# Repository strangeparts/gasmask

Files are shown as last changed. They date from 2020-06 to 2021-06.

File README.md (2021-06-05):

# Open Source Gas Mask

<div align="center">
  Animation of gas mask configurations
  <p style="display: block; max-width: 800px; margin: 0 auto;" align="left">
    NOTE:<br />
    These are preliminary designs that still need testing and refinement. Do not rely on this to save your life just yet.
    <br />
    Configurations shown above are for illustrative purposes and do not imply validation. Always be sure to read and understand the documentation, recommendations, and limitations of every component you build.
    </p>
</div>

## About

This is an open source 3D printable gas mask design. It consists of 3 main components - the mask itself, the filter canister, and the exhale valve. Each component in turn may consist of multiple parts. The documents contained in this repository provide information to help you select and build each component.

## Components

### Mask

Masks are either full face or half face, depending on whether they protect the mouth/nose and eyes or just the mouth and nose. Half face masks are simpler, cheaper, and faster to make in the event that eye protection is not necessary or is accomplished with separate equipment.

All masks in this repository use 40mm NATO threads to connect to other components when necessary. This also means that commercially available 40mm NATO threaded filter canisters are directly compatible with these masks. Commercial filter canisters with different connector standards may be used with the masks in this repository by using an adapter from the `adapters` folder.

See the `masks` folder readme for a comparison of mask designs.

### Filter

If filters are commercially available, they are always preferable to homemade filters. However, in the event that filter supply is expensive or unavailable, the included designs allow for homemade filters. All masks in this repository use standard 40mm NATO threaded filter canisters, which are located in `filters/NATO_40mm`.

If an adapter is in use to convert NATO threads to a different standard, you may want to build the appropriate filter canister found in the appropriate subfolder in `filters`. This is especially useful if you wish to easily switch between commercially available filters and homemade filters without having to remove the adapter.

The filter material is activated charcoal - you can buy this at any pet store. Put a layer of cotton batting in the bottom of the canister, then fill with activated charcoal, then put another layer of cotton on top, and connect the canister into the mask. See the documentation included with the specific filter design for more detailed instructions.

### Valve

The use of an exhale valve reduces the chance of asphyxiation due to re-breathing the same air, as well as prolonging the life of the filter media and mitigating visor fogging on full face masks. All masks in this repository should contain provisions for an exhale valve. For your safety, ensure every assembled mask has an exhale valve installed and operating properly. The mask documentation should include guidance on installing the exhale valve.

See the `valves` folder readme for an overview of valves.

### Adapters

To ensure compatibility between components in this repository, all connections use standard 40mm NATO threads. As a result, adapters are required to use filter canisters of a different connector standard. The `adapters` folder contains a catalog of 3D printable adapters for converting the NATO threads of the mask to many other standards.

* When using an alternate connector type, ensure that a seal is properly made and any required gaskets or additional materials are in place.
* It may make assembly and use of the mask easier if the adapter is permanently glued to the mask. This is a good option if support for multiple connector standards is not needed.

## Safety Warnings
***This mask is still in development. You should not use this in a real world situation until the mask is done, and any testing you do should be in a controlled environment with someone else present !!!***

1. Print Material: PLA can be brittle and sharp in the event that it breaks. It is recommended to use PETG or Nylon if possible, especially if the risks of PLA shattering could be an issue in the environment you plan on using it or if you expect the mask to be subjected to stresses or impacts.
2. Face Gasket: When using a hard plastic material, it is extremely unlikely that a proper seal will form between the mask and the user's face. Some form of gasket or appropriate foam should be added around the edge of the mask to ensure an airtight seal.
3. Fit / Seal / Leak Testing: It is highly recommended to test the mask for leaks and fit quality.
4. Exhale / Vent Valve: The amount of dead space inside the mask and filters can lead to a risk of asphyxiation. All masks in this repository have provisions for installing an exhale valve. Please be sure to assemble and install one in every mask.
5. Gaskets / Glue: Every connection point between parts must have an airtight seal with the exception of filter canister lids on the dirty side of the filter media. See the documentation included with each part to ensure the proper seal is achieved. Alternatively, parts that do not need to be disassembled may be glued together with the appropriate glue.

## Contributing

Pull requests welcome! Join the discussion on [Discord](https://discord.gg/7X2bSzY).

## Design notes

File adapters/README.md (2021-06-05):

# Adapters

The masks in this repository are based on the NATO 40mm respirator thread standard. In order to allow these designs to interoperate with a wider variety of off-the-shelf components, this folder contains additional adapters which will convert the NATO threading to alternate standards. This is useful for anyone who would like to use off the shelf filters that are not NATO threaded.

## External Designs

| Filter Connector | Name / Link | Creator | Connectors Tested |
| - | - | - | - |
| 3M Bayonet | [40MM NATO (RD40x1/7) to 3M™ Filter Adapter](https://www.thingiverse.com/thing:4245358) | AgapeIngenium | &#10007; |
| AOSafety R5700 8051 Bayonet | [40MM NATO (RD40X1/7) to AOSafety® R5700 8051 Bayonet Filter Adapter](https://www.thingiverse.com/thing:4265538) | AgapeIngenium | &#10007; |
| AOSafety Threaded | [40MM NATO (RD40X1/7) to AOSafety® Threaded Filter Adapter](https://www.thingiverse.com/thing:4273365) | AgapeIngenium | &#10007; |
| Delta Plus M3000 Mars Series | [40MM NATO (RD40X1/7) to Delta Plus M3000 Mars Series Filter Adapter](https://www.thingiverse.com/thing:4311197) | AgapeIngenium | &#10007; |
| Delta Plus M6000 Jupiter Series | [40MM NATO (RD40X1/7) to Delta Plus M6000 Jupiter Series Filter Adapter](https://www.thingiverse.com/thing:4311200) | AgapeIngenium | &#10007; |
| Draeger X-plore (3000/5000 Series) | [40MM NATO (RD40x1/7) to Draeger X-plore® Filter (3000/5000 Series) Adapter](https://www.thingiverse.com/thing:4329276) | AgapeIngenium | &#10007; |
| ENHA Rockman 7300 Series | [40MM NATO (RD40x1/7) to ENHA Rockman 7300 Series Filter Adapter](https://www.thingiverse.com/thing:4329610) | AgapeIngenium | &#10007; |
| GOST | [NATO to GOST & GOST to NATO (RD40x1/7-KR40H4) Adapter Set](https://www.thingiverse.com/thing:4321450) | AgapeIngenium | &#10007; |
| Honeywell/Honeywell North | [40MM NATO (RD40X1/7) to Honeywell/Honeywell North® Filter Adapter](https://www.thingiverse.com/thing:4268775) | AgapeIngenium | &#10007; |
| Honeywell Safety Sperian / Survivair ValuAir Respirator (Bayonet) | [40MM NATO (RD40x1/7) to Honeywell Safety Sperian® /Survivair™ ValuAir® Respirator (Bayonet) Filter Adapter](https://www.thingiverse.com/thing:4345345) | AgapeIngenium | &#10007; |
| Honeywell Sperian | [40MM NATO (RD40X1/7) to Honeywell Sperian® Filter Adapter](https://www.thingiverse.com/thing:4297348) | AgapeIngenium | &#10007; |
| JSP Force8 | [40MM NATO (RD40X1/7) to JSP® Force™8 Filter Adapter](https://www.thingiverse.com/thing:4294203) | AgapeIngenium | &#10007; |
| MEDOP EUROPA Comfort Series | [40MM NATO (RD40x1/7) to MEDOP Threaded Filter (EUROPA Comfort Series) Adapter](https://www.thingiverse.com/thing:4380984) | AgapeIngenium | &#10007; |
| Milla EURMASK ETNA (Bayonet) Series | [40MM NATO (RD40x1/7) to Milla EURMASK® ETNA (Bayonet) Series Filter Adapter](https://www.thingiverse.com/thing:4342320) | AgapeIngenium | &#10007; |
| Milla EURMASK (Uno/New) Series Threaded | [40MM NATO (RD40x1/7) to Milla EURMASK® (Uno/New) Series Threaded Filter Adapter](https://www.thingiverse.com/thing:4342343) | AgapeIngenium | &#10007; |
| Moldex 7000/9000 Series EasyLock Bayonet | [40MM NATO (RD40X1/7) to Moldex® 7000/9000 Series EasyLock® Bayonet Filter Adapter](https://www.thingiverse.com/thing:4275446) | AgapeIngenium | &#10007; |
| Moldex 8000 | [40MM NATO (RD40x1/7) to Moldex® 8000 Series Filter Adapter](https://www.thingiverse.com/thing:4422042) | AgapeIngenium | &#10007; |
| MSA Bayonet | [40MM NATO (RD40X1/7) to MSA® Bayonet Filter Adapter](https://www.thingiverse.com/thing:4265715) | AgapeIngenium | &#10007; |
| MSA Comfo Classic Threaded | [40MM NATO (RD40X1/7) to MSA® Comfo Classic Threaded Filter Adapter](https://www.thingiverse.com/thing:4267676) | AgapeIngenium | &#10007; |
| MSA Phalanx | [40MM NATO (RD40x1/7) to MSA® Phalanx Filter Adapter](https://www.thingiverse.com/thing:4399965) | AgapeIngenium | &#10007; |
| Portwest Bayonet | [40MM NATO (RD40X1/7) to Portwest® Bayonet Filter Adapter](https://www.thingiverse.com/thing:4273464) | AgapeIngenium | &#10007; |
| Scott 742 Series (Bayonet) | [40MM NATO (RD40x1/7) to Scott® 742 Series (Bayonet) Filter Adapter](https://www.thingiverse.com/thing:4347531) | AgapeIngenium | &#10007; |
| Secura BC Bayonet | [40MM NATO (RD40X1/7) to Secura BC Bayonet Filter Adapter](https://www.thingiverse.com/thing:4294187) | AgapeIngenium | &#10007; |
| Spasciani Bayonet (Duetta and Duo) 2000 Series | [40MM NATO (RD40x1/7) to Spasciani Bayonet (Duetta and Duo) 2000 Series Filter Adapter](https://www.thingiverse.com/thing:4378232) | AgapeIngenium | &#10007; |
| Sundstrom SR Series (SR100/200/900) | [40MM NATO (RD40x1/7) to Sundstrom SR Series Filter (SR100/200/900) Adapter](https://www.thingiverse.com/thing:4338105) | AgapeIngenium | &#10007; |

## Misc
NATO 40mm female-female coupler: https://www.thingiverse.com/thing:4304055 by AgapeIngenium

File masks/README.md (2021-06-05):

# Masks

## Designs

| Name | Size | Ports | Description | Print Time | Status |
| - | - | - | - | - | - |
| SmoothPrintedMask | Full Face | 2x NATO | Scotty's original mask design with NATO ports | - | - |
| SplineRespirator | Half Face | 3x NATO | Untested and incomplete prototype. Features smooth contours. | - | Unfinished |

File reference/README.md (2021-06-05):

# Reference
These are bits and pieces we used in building the mask and accessories!

## NATO 40mm Thread
This pair of thread models was designed based on the NATO 40mm specification for respiratory devices. It is also known as STANAG 4155, EN 148-1, or Rd 40x1/7". These models are provided to assist with the creation of masks, filter canisters, exhale valves, etc. that are compatible with other components in this repository.

These components were designed using information from this [EN-148-1 document](https://web.archive.org/web/20210329023351/https://cdn.standards.iteh.ai/samples/60082/4152181d809d48b2968c8c22062d4d21/SIST-EN-148-1-2019.pdf).

### Male
The male thread is designed to 20mm in length in order to meet the minimum requirement of 14.5mm per the specification. This helps ensure that it will reach the back of the female thread and press against the gasket to form an airtight seal. The top of the male thread model (positive Z) is chamfered for easier alignment when attaching components together. The bottom of the male thread (resting on the Z=0 plane) is not chamfered and is intended to be fused to the rest of the component.

### Female
The female thread is designed to a depth of 12mm, with a 2mm thick backstop. The depth is intended to be shallow enough to allow any male thread which follows the specification, and thus is 14.5mm or more in length, to reach the backstop and press the gasket to form an airtight seal.

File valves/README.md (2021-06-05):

# Valves
Due to the potentially large volume of filter canisters, a one way exhale valve is required to ensure a flow of fresh air and to reduce the chance of asphyxiation. Every mask in this repository should have space for an exhale valve. Refer to the documentation accompanying the mask for placement instructions.

## Designs

| Name | Description | Print Time | Status |
| - | - | - | - |
| FullyPrintedValve | Requires no extra parts. Not a perfect seal but useful if resources are limited. Can be augmented to provide an excellent seal. | ~2h | Tested |
| BalloonValve | Requires a latex glove or thin balloon. Better if your craft skills are superior to your printer tune. | ~2h | Experimental |

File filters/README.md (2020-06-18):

# Filters

This folder contains designs for respirator filters. Designs are organized into folders based on the connector type. The masks in this repo are based on the NATO thread standard. Filters with other connector standards are available in case you want to install an adapter on your mask to make it compatible with a different standard while maintaining the ability to easily use homemade filters.

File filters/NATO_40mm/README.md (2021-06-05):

# NATO 40mm Filters

## Designs

| Name | Description | Connector Tested | Assembled Length (mm) | Internal Volume (cm<sup>3</sup>) |
| - | - | - | - | - |
| BottleFilterAdapter | Allows using plastic bottles as a filter body | &#10003; | Variable | Variable |
| CustomizableAF | Fully 3D printed filter canister body | &#10003; | 120 | ~200 |

## External Designs

> Note: These designs may not be tested or validated

| Name | Connector Tested | Assembled Length (mm) | Internal Volume (cm<sup>3</sup>) |
| - | - | - | - |
| [Reusable gas mask filter - 40mm thread by Bastrym](https://www.thingiverse.com/thing:4236518) | &#10003; |  |  |

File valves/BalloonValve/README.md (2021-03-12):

# Balloon Valve

This valve was originally designed by @sophmur for respirator and cloth mask use and posted to [Thingiverse](https://www.thingiverse.com/thing:4753245).

We have reworked the design into a NATO 40mm package for our use with this project. The assembly is very similar to the `FullyPrinterValve` since we reused much of the design.

Between the two pieces you should place a circular piece of a latex glove type material (thin, light, non-breathable). We are still working on a full assembly guide but for now we recommend marking the shape and size of the `BalloonValve-Inlet` and using scissors, you can also use a sharp knife if you find that easier.

As for assembly, if you find it difficult to stretch out the latex properly, you can put the `BalloonValve-Inlet` piece up against a vacuum cleaner to hold the membrane stretched out and then put on the `BalloonValve-Body` piece onto it. It should snap right together.

<p align="center">
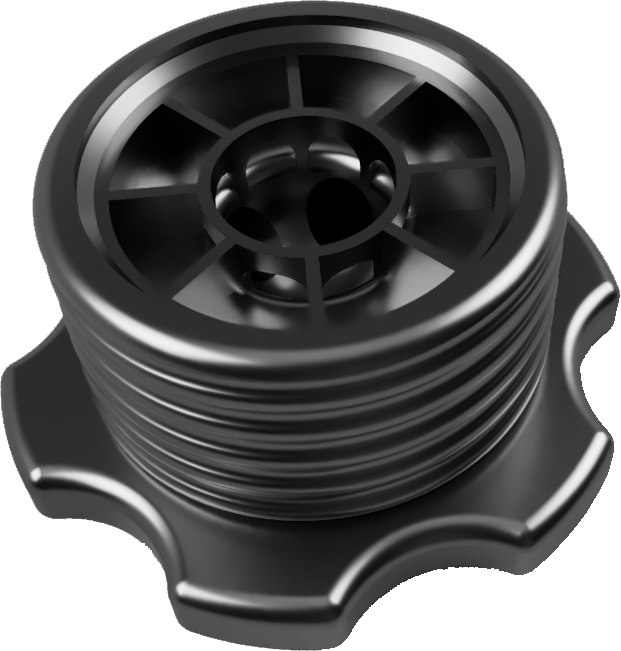
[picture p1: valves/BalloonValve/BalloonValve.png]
  
 </p>

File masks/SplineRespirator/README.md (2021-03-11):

# SplineRespirator

<p align="center">
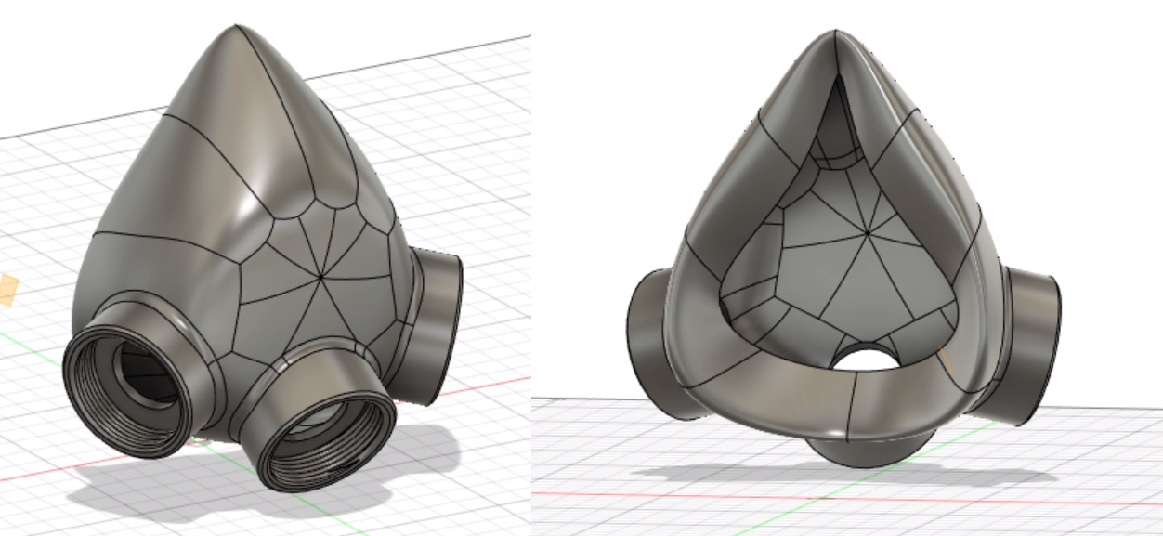
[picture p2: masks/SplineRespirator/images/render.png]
Render of the respirator body
  
</p>

This is a prototype half face respirator with 3 NATO ports. The aim of this design is to use silicone and a mold to form a better seal.

## Safety Warnings

* This design is not complete. Do not use it.

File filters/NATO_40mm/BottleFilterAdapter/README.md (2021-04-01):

# BottleFilterAdapter

<p align="center">
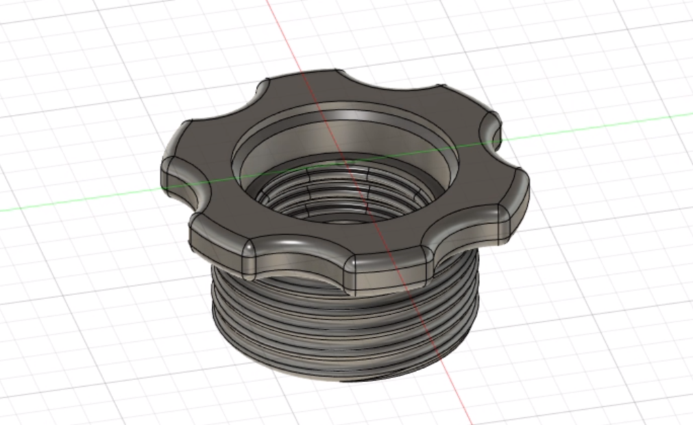
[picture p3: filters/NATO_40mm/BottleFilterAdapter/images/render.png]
Render of the respirator body
  
</p>

This component allows using water bottles / carbonated soft drink bottles to build homemade filters.

The threads on this design were created using information from [this specification](https://web.archive.org/web/20210329170423/https://www.isbt.com/assets/Threadspecs/pco1810.pdf).

## Overview

There are 2 common standards for plastic bottles - PCO-1810 and PCO-1881. The first is the older standard, and the second is the newer standard with a lower profile and less material.

Currently this design only works with PCO-1810, a PCO-1881 variant may be added later.

## Building

### Materials

1. The printed adapter
2. A plastic water bottle or soft drink bottle
3. A US #18 size o-ring (metric 1.78x18.77mm) (preferred) or glue / epoxy suitable for plastics

### Print Parameters

* Print Time: Approximately 1 hour 45 minutes
* Nozzle Size: 0.4mm
* Layer Height: 0.2mm
* Infill: 15%
* Supports: On build plate only (prevents support material in between threads, aiding with support removal)
* Walls: 2

### Assembly

1. Print the adapter in the default orientation - with the knob on the print surface.
2. Carefully remove all the support material from the bottle threads.
3. Remove the bottle cap safety seal from the bottle (the plastic ring that detaches from the cap when opening), and replace it with the o-ring. Alternatively, add glue to the bottle and adapter bottle threads.

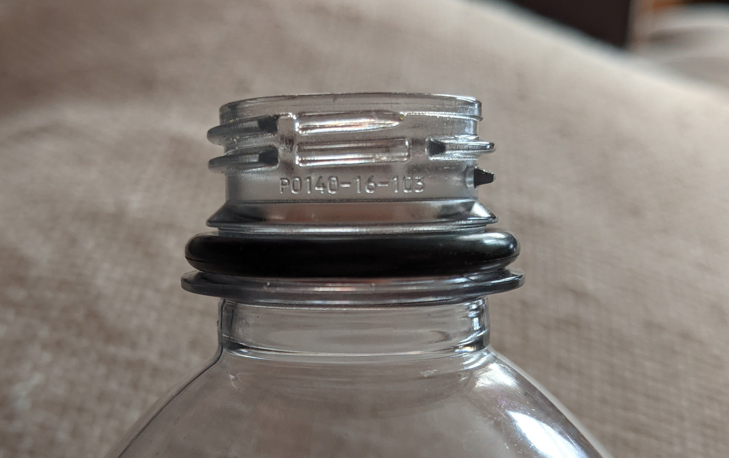
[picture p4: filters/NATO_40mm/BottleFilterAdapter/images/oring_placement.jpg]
Image of proper o-ring placement
  

4. Screw the bottle filter into the adapter until the o-ring is fully seated.

## Safety Warnings

* This design will not achieve a seal if an o-ring or glue is not used. Always test the seal to ensure your selection of o-ring/glue is effective.

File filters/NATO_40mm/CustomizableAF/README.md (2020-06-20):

# CustomizableAF

AF ofcourse meaning Air Filter

is a modular airfilter system. You can pick a main canister based on size and a cap based on your preference. The connection between those is made via an M90 thread, with tolerance added on the cap side to account for the lower precision of household 3d printers.

Feel free to itterate and create more designs.

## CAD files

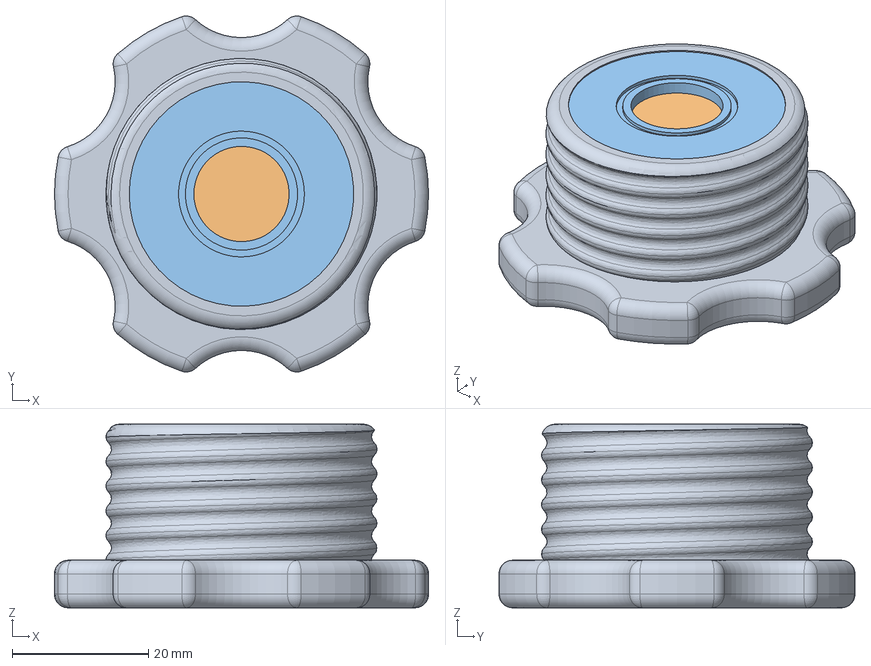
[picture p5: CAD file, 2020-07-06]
valves/FullyPrintedValve/FullyPrintedValve.stp
55.0 x 52.3 x 27.0 mm
Valve Body
Diaphragm
Inlet

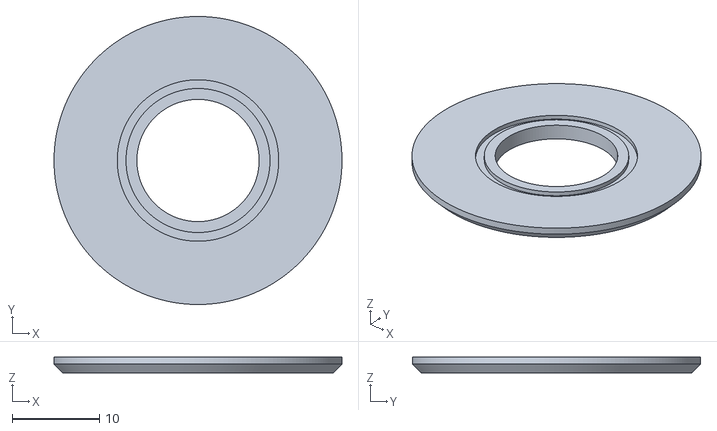
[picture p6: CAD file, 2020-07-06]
valves/FullyPrintedValve/FullyPrintedValve-Inlet.stl
33.0 x 33.0 x 1.80

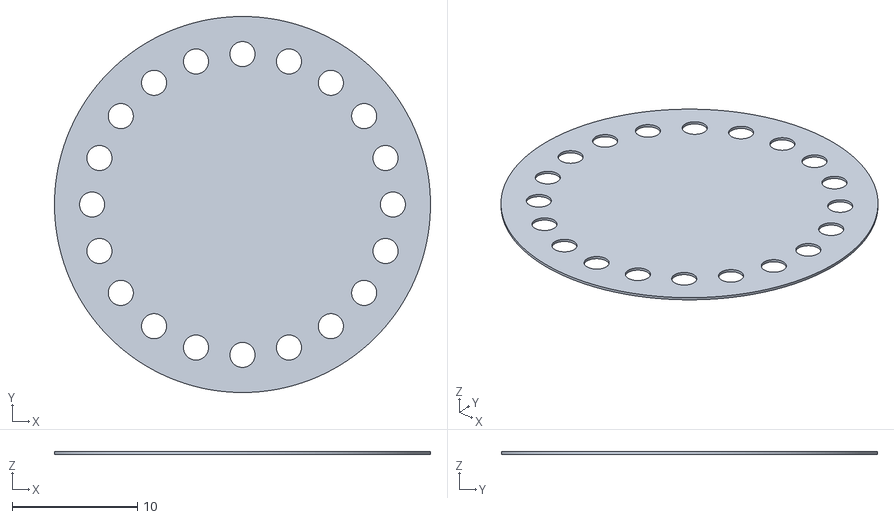
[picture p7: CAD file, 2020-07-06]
valves/FullyPrintedValve/FullyPrintedValve-Diaphragm.stl
30.0 x 30.0 x 0.2

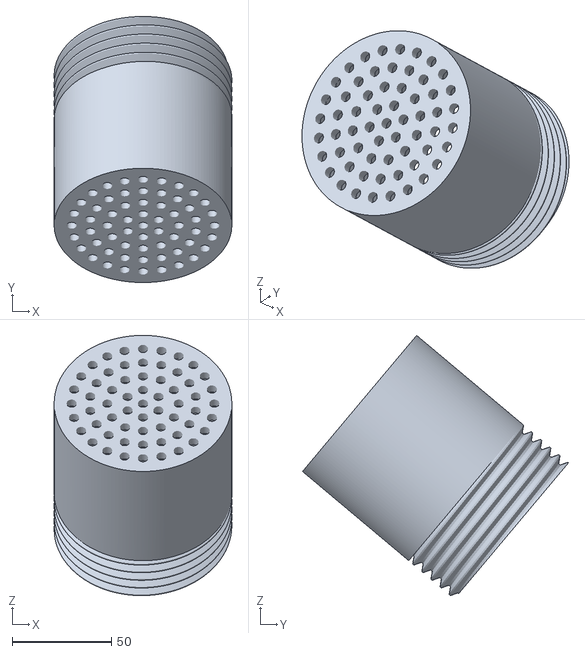
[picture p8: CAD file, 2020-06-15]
Canister.stl
89.6 x 134.2 x 131.3

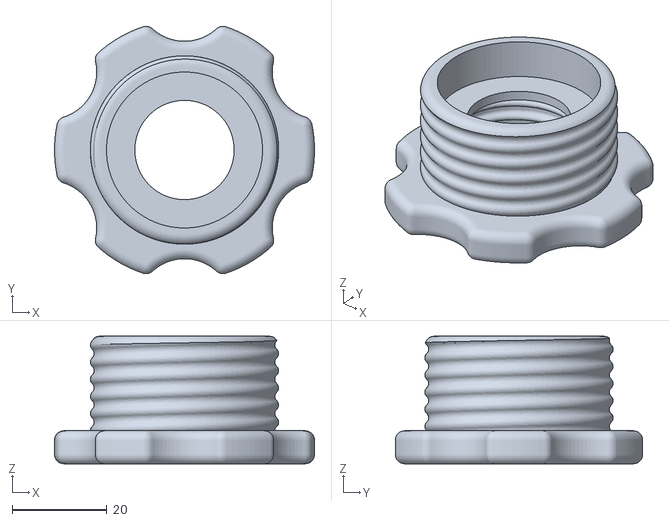
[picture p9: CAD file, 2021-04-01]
filters/NATO_40mm/BottleFilterAdapter/BottleFilterAdapter.stl
55.0 x 52.3 x 27.0

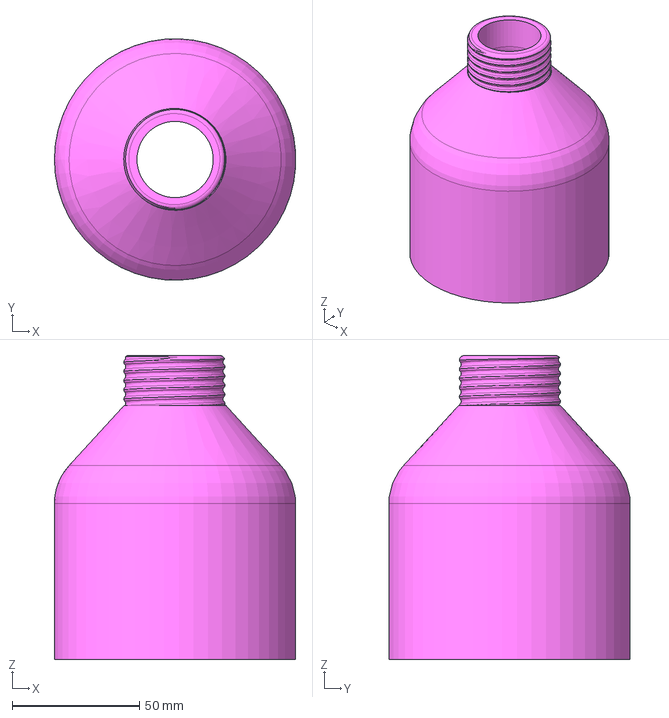
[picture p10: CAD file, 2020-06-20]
filters/NATO_40mm/CustomizableAF/120mm_Canister/120mm_Canister (NATO mount).step
94.9 x 95.0 x 119.6 mm

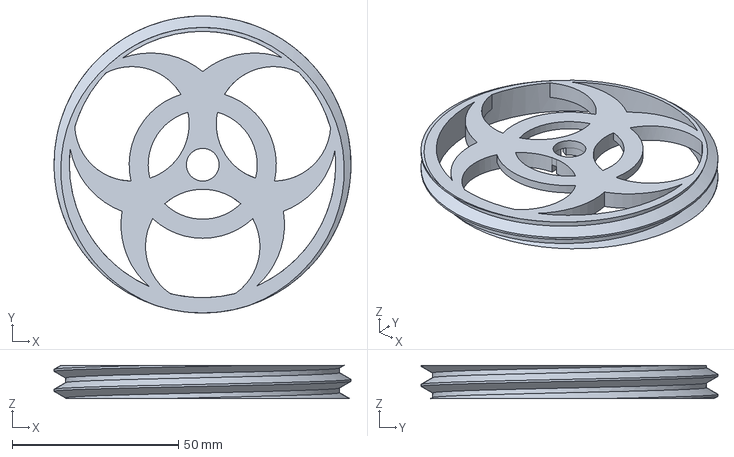
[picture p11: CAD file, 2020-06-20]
filters/NATO_40mm/CustomizableAF/SeriousOne/SeriousOne.step
89.2 x 89.2 x 10.0 mm

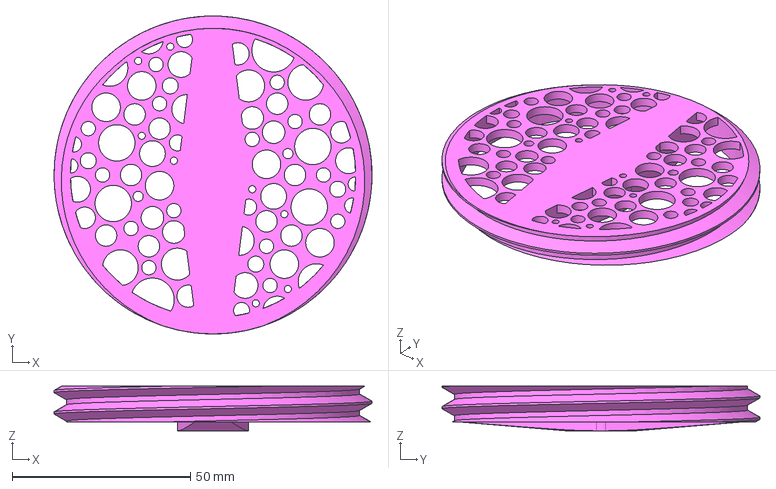
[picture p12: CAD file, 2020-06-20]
filters/NATO_40mm/CustomizableAF/Trypophobic9000/Trypophopic9000.step
89.2 x 89.2 x 12.5 mm

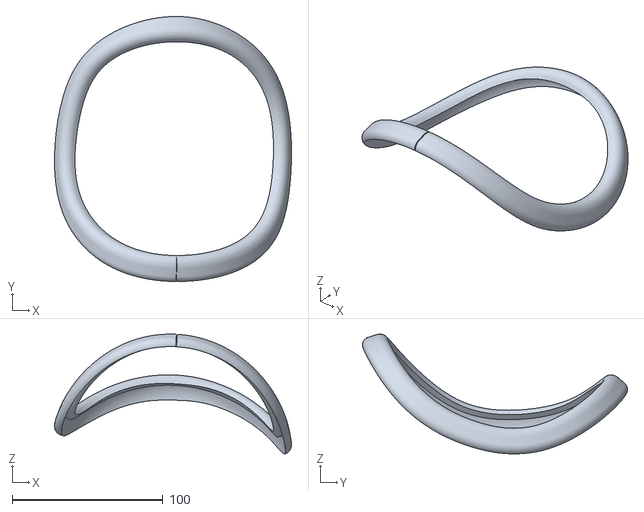
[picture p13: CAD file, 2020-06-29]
masks/SmoothPrintedMask/face_shield_gasket.stl
157.5 x 176.1 x 79.6

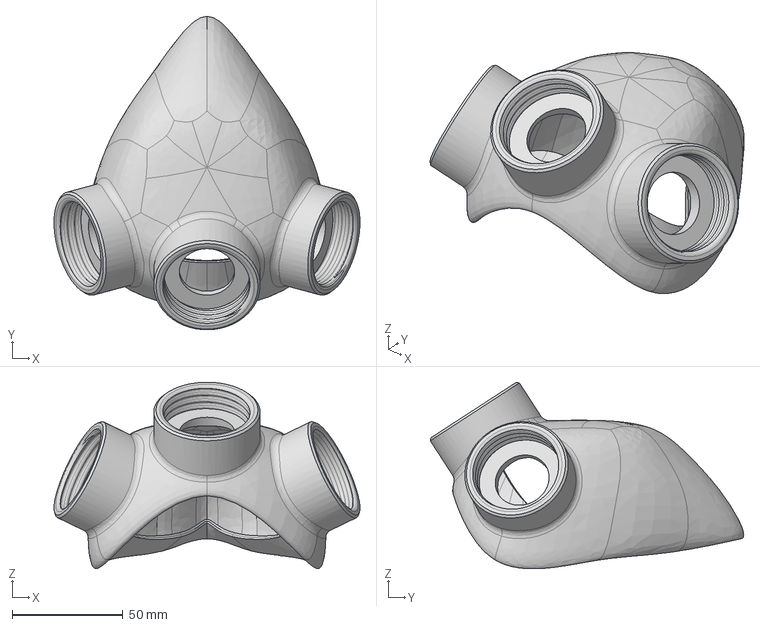
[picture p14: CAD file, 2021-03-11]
masks/SplineRespirator/SplineRespirator.step
138.1 x 141.5 x 84.1 mm

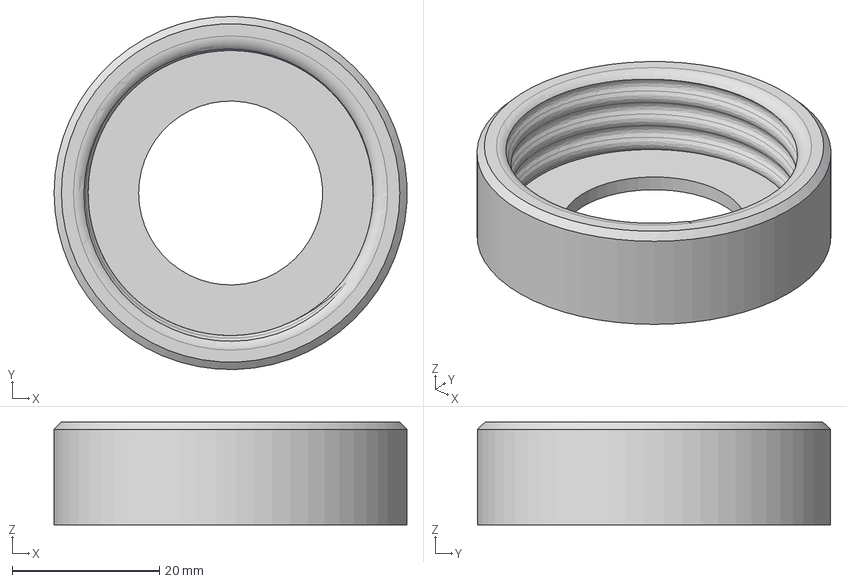
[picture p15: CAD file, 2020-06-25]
reference/NATO_40mm_Thread_Female.stp
48.0 x 48.0 x 14.0 mm

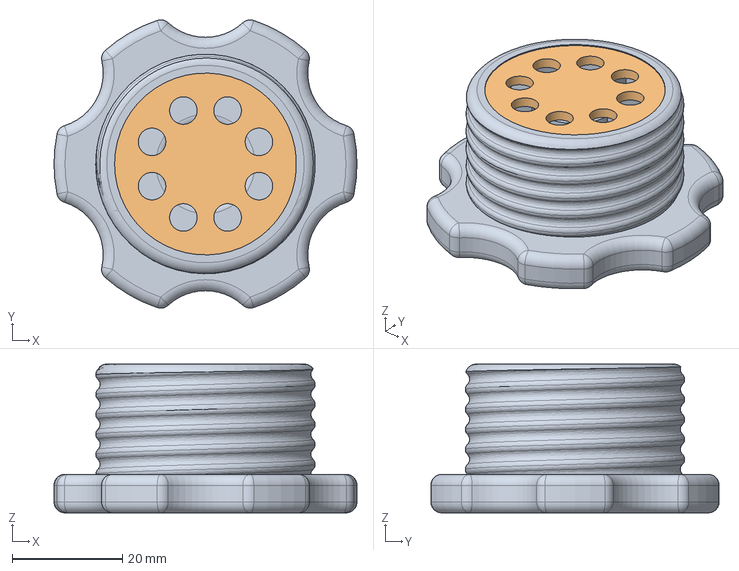
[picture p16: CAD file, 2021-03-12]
valves/BalloonValve/BalloonValve.step
55.0 x 52.3 x 27.0 mm
Valve Body
Inlet

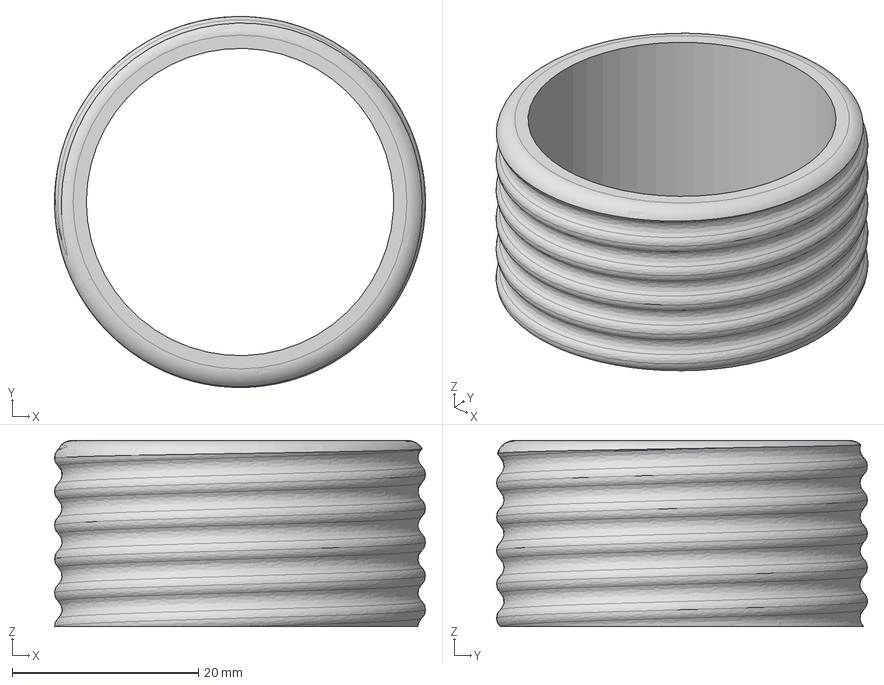
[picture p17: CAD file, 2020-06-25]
reference/NATO_40mm_Thread_Male.stp
39.8 x 39.9 x 20.0 mm

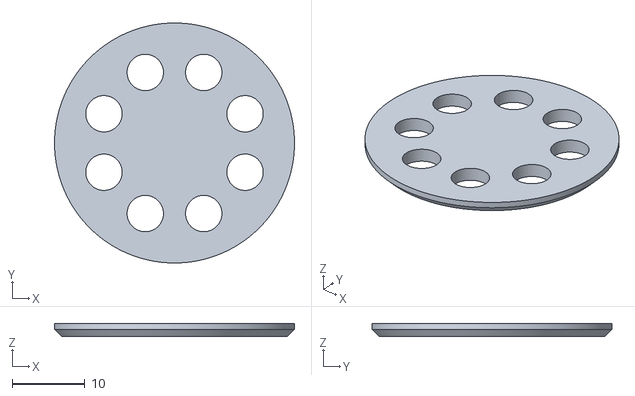
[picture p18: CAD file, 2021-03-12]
valves/BalloonValve/BalloonValve-Inlet.stl
33.0 x 33.0 x 1.80

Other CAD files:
Face shield gasket.stl
legacy/Face shield gasket.stl
filters/NATO_40mm/BottleFilterAdapter/BottleFilterAdapter.f3z
filters/NATO_40mm/CustomizableAF/120mm_Canister/120mm_Canister (NATO mount).f3z
filters/NATO_40mm/CustomizableAF/120mm_Canister/120mm_Canister (NATO mount).stl
filters/NATO_40mm/CustomizableAF/SeriousOne/SeriousOne.f3z
filters/NATO_40mm/CustomizableAF/SeriousOne/SeriousOne.stl
filters/NATO_40mm/CustomizableAF/Trypophobic9000/Trypophopic9000.f3d
filters/NATO_40mm/CustomizableAF/Trypophobic9000/Trypophopic9000.stl
masks/SplineRespirator/SplineRespirator.f3z
reference/NATO_40mm_Thread_Female.f3d
reference/NATO_40mm_Thread_Female.stl
reference/NATO_40mm_Thread_Male.f3d
reference/NATO_40mm_Thread_Male.stl
valves/BalloonValve/BalloonValve.f3z
valves/FullyPrintedValve/FullyPrintedValve.f3z

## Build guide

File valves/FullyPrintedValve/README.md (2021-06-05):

# FullyPrintedValve

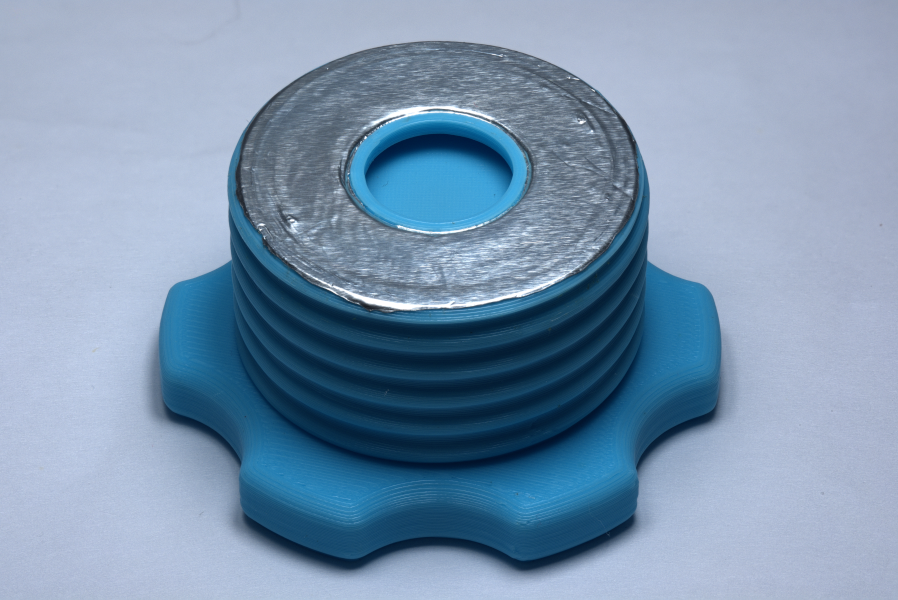
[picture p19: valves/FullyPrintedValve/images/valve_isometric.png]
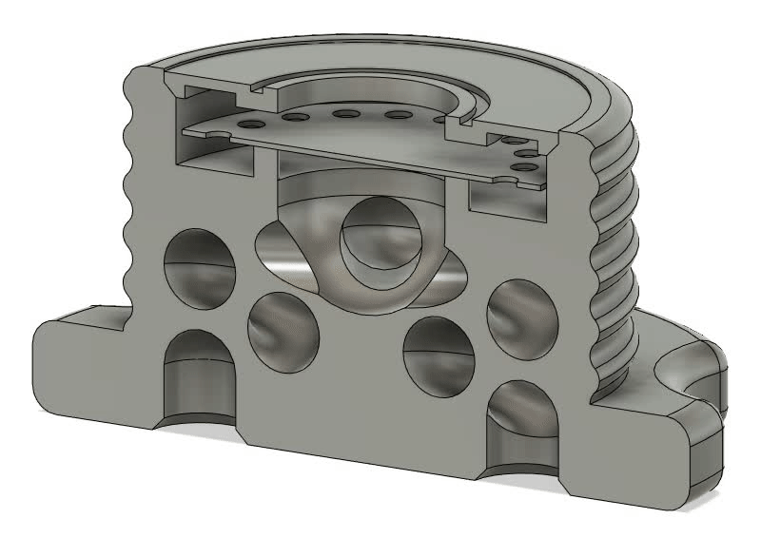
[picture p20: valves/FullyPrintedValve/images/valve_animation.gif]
<br />

This valve was designed to be completely 3D printed, in the event that few other materials are available. Currently it requires aluminum tape or duct tape, both of which are available at hardware stores. The seal is pretty good, but not perfect, and still requires testing to determine whether it will fully protect the wearer.

## Overview

The valve comes in 3 parts:

* The main body which consists of the threads, tightening knob, and valve chamber
* The diaphragm, which is a 0.2mm thin disc with a ring of holes around the edge
* The inlet plate, which is a 1.8mm thick disc with a hole in the center

## Building

### Materials

In order to build this valve, you will need:
1. 3D printer with a smooth print surface (Flexible smooth PEI spring steel preferred, glass should work)
2. Aluminum foil tape, 3.9mil preferred (Duct tape or Gorilla tape can also work, albeit less effectively)
3. Scissors or means of trimming the tape (Aluminum tape can be trimmed by tearing carefully)
4. A sharp object such as a craft knife (A fingernail can work for Aluminum tape)

### Print Parameters
* Print Time: Approximately 2 hours
* Nozzle Size: 0.4mm
* Layer Height: 0.2mm
* Infill: 15%
* Supports: None
* Walls: 2

### Assembly

1. Print all 3 parts in the default orientation. The tightening knob should be on the build plate with the threaded end pointing upwards.
2. Let the build plate cool before removing to prevent warping the sealing surfaces.
3. If the build plate is flexible, flex it in 2 directions by turning the build plate 90 degrees in between. Repeat until the main body and inlet place can be lifted off.
4. Continue bending the plate until the diaphragm can slide freely off of the bed. If the build plate is not flexible, try to remove the diaphragm without bending it if possible.
5. Place the diaphragm into the threaded end of the main body, so that it rests on top of the pins inside. The smooth side of the diaphragm (the side that was face down on the bed) should be facing upwards.
6. Be sure the smooth side of the diaphragm is facing upwards for the best seal quality.
7. Press fit the inlet plate into the hole to capture the diaphragm. Ensure that the inlet plate is oriented so the side that was touching the print bed is facing down, towards the diaphragm. The inlet plate should be flush with the body when fully seated.
8. Use a piece of aluminum foil or duct tape to over the inlet plate, pressing to ensure a good seal.
9. Trim the excess tape, ensuring that the tape extends completely to the edge and does not stop too close to the seam between the valve body and inlet plate. A little extra is fine, but too little will allow a leak. If tape is not available, glue may suffice at your own risk.
10. Using a fingernail or sharp tool, score or cut the ridge around the center hole of the inlet plate and remove the resulting circle of tape to allow air to flow through the center hole. Avoid putting anything through the air hole to avoid damaging the diaphragm.

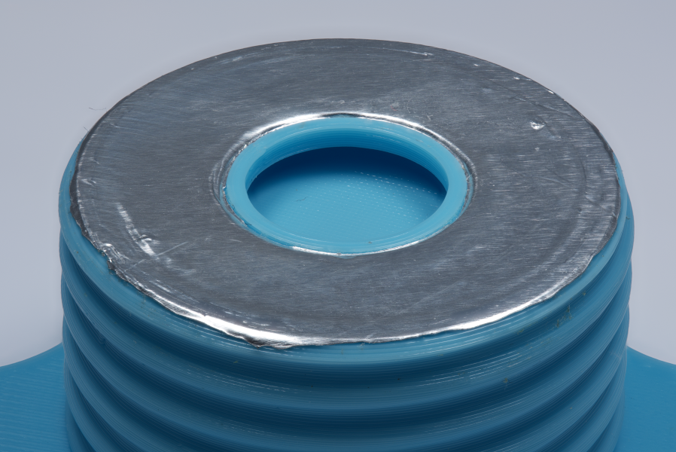
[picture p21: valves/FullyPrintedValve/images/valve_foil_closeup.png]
  

11. Finally, you can test the valve by putting your mouth on either end. Air should be able to flow from the inlet plate through to the end with the knob. Airflow in the opposite direction should be blocked.

## Safety Warnings

* This design relies on a properly calibrated first layer. If the 1 layer thick diaphragm has holes near the center, then the valve will not operate properly. Holes around the edge are acceptable. Ideally, the diaphragm should be strong enough that the layer lines cannot be pulled apart with bare hands unless it is folded or torn from the edge.
* Refer to the documentation for your face mask for the proper location to install the valve. This design is intended to be installed on the outside of the mask. Installing this on the inside will allow air to pass into the mask through the valve but not out.
* The NATO connector specifies a gasket to be used at the bottom of the female thread. If this gasket is not present, consider using an appropriate glue to form an airtight seal. Failure to do either can result in a leaky mask that will not protect you.
* If glue is used, ensure that the glue doesn't seep into the chamber containing the diaphragm, which could cause the diaphragm to be glued into place rendering the valve non-functional.
* Always test the final assembly with fit/leak testing procedures to ensure the valve performs acceptably before putting it into service.

## Testing Results
| Test | Description | Tester | Result | Notes |
| - | - | - | - | - |
| Banana Oil | Valve was installed into a 3M half-face mask and banana oil was held at the exhale port. | Stephen304 | Pass |  No banana scent was detected for the duration of 30 seconds. |
| Banana Oil | Valve was installed into a 3M half-face mask and banana oil was held at the exhale port. Short rapid breaths were taken, just enough to open and close the valve repeatedly. | Stephen304 | Pass |  No banana scent was detected for the duration of 30 seconds. |

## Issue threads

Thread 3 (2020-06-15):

Design is to huge for most 3d printers

schaurian, 2020-06-15:
This might not be an issue. But it definitely a big disadvantage.  I can't fit it on my Prusa mk3s. Which is a very common 3d printer. Maybe the Part from the filter could be closer to the mouth?
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

tytytyty74, 2020-06-16:
I have to agree with you there, on my ender 3 there's a single orientation it will fit, which is very difficult to print, requiring a significant amount of support material, upping the print time to over 60 hours

schaurian, 2020-06-16:
> I have to agree with you there, on my ender 3 there's a single orientation it will fit, which is very difficult to print, requiring a significant amount of support material, upping the print time to over 60 hours

Do you have and idea how to improve it. I have some skills in fusion 360. Ideally it would be easy to print on any printer without any support material.

stephen304, 2020-06-17:
Just to bridge some of the discord discussion to here, it seems the direction we are moving is to separate the canister from the mask and use NATO 40mm threads so that the mask can be compatible with standard canisters and a wide variety of adapters to practically any other canister, also allowing the custom canister to be removed without opening up the contents. That will remove the top of the canister completely from the model which should really help it fit on more print beds. There are some experienced cadders who dropped into discord so we should coordinate to make sure no work is duplicated. Somebody also made a fusion360 cloud team so collaboration will probably happen there, maybe we can sync it back here periodically.

Also we don't have the female nato 40mm threads yet, but we successfully printed the male threads and verified it with a commercial mask.

stephen304, 2020-07-04:
@schaurian A modified mask is now in the masks folder if you'd like to check that out. It should be easier to fit it on a prusa

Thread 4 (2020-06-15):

Exhalation valve and dead space

skaihoj, 2020-06-15:
I know hhis has been mentioned elsewhere, but this seems like the place to stpre and organize ideas.

The device needs an exhalation valve. It needs to be located on the other side if the "inner mask", and the inner mask should not seal against the face. It should preferably be made such that the fresh air arrives on the outside of the inner mask, and is exhaled inside it.

Dead space should be minimised. This is the volume of gas that gets inhaled again after being exhaled. The current design has so much dead space, that it might cause carbon dioxide poisoning. Much of this can be removed with a carefully placed exhalation valve.

Liam-Stark, 2020-06-15:
Would two check valves, placed on either side of the main valve, be a reasonable solution? Is there a better place for exhalation valve(s)?

Also, can you elaborate on the third sentence? Maybe a diagram of the suggested airflow? I just had a hard time following lol.

skaihoj, 2020-06-15:
The filter will usually have high resistance to airflow, so only one check valve is needed, and no other valves of any kind.

If you are breahing into something like a snorkel, some of the air you exhale will be left in the snorkel. When you inhale again, this sir goes back in your lungs. If the volume of such a snorkel is large enough, no new air will enter your lungs. if the same air gets used again and again, you will suffocate. See also https://en.wikipedia.org/wiki/Dead_space_(physiology)#Mechanical_dead_space

In the current design, the volume of the mask and the filter both contribute to this dead space.  Adding an exhalation valve will remove the filter from the volume getting breathed back in.

stephen304, 2020-06-17:
There have been a couple valve design ideas going around the discord, complexity and materials that may be hard for some people to find can be a problem with using 1 specific valve design, so we have the idea of using some standard threaded hole that we can design a plug for, with our valves embedded in it. That way assemblers can choose an appropriate exhale valve based on their requirements and available materials.

As far as I can tell these are the remaining tasks to resolve this:
* Decide on a location for the vent port
  * I think we all agree that it should vent from the inner mask.
  * If we add a new inlet to the side of the mask (which would intake air to the larger space, maybe this would help reduce fogging?) we could reuse the existing port location for the vent valve
  * We could also add a second port above or below the current one and use one as in and one as out - I'm not sure whether you would want a tube to get the intake into the larger space rather than the mouth area
* Decide on a threading for the vent port
  * I initially wanted to just use nato since we're already working with it, but some suggested that making it smaller/different would help reduce mistakes. I don't really have an opinion on this as long as everyone agrees
* Add a channel to the outside of the vent port to reduce the chance of contamination ingress via backflow.
  * This is my idea to make the mask more resistant to less perfect valve designs. My fully 3D printed one way valve does allow a small amount of air to ingress before the valve fully closes. I have to test to determine whether it's just air inside the valve or whether any air outside the valve actually gets in, but I think adding this feature will be good to enable a wider variety of valve designs. Probably this will happen last and may not be necessary - we'll see :)

If you haven't joined the discord, a lot of discussion is going on there. Collaboration will probably happen in fusion360 cloud, and maybe changes will be synced back here periodically.

skaihoj, 2020-06-18:
I am on the discord, but i find the discussion there hard to follow, since there is only one room there for discussing the gas mask. all the discussion going on in one place makes it very time consuming to participate.

* We should only need one check valve, if it works properly. The resistance to airflow in the filter should be enough to prevent backflow.
* The threading for the vent port should mainly be decided by what will actually work on a 3D printer. 3D printing threads that last can be hard.

stephen304, 2020-06-18:
@skaihoj Yeah it's been a lot of chatter in there. Good to know about the valves. For the thread, a lot of threadings print pretty well, even down to small M sizes. The NATO threads are actually pretty huge, so there's no problem with the filter port. Our test pieces so far have worked with off the shelf NATO masks. If we chose a different thread for the vent port then it will likely be a lot finer of a thread. I don't really have a strong opinion on the vent port thread so I'll probably just defer to those with engineering experience.

stephen304, 2020-07-04:
I believe this is now resolved as my one way valve has been tested and the masks have been redesigned to accept a threaded valve assembly. We can probably close this issue and any tangential concerns can go in a new issue.

skaihoj, 2020-07-06:
That seems reasonable. From what i've seen on the discord, you seem to have any issues raised here under control.

Closed 2020-07-06.

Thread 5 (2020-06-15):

Exhaust valve needed

Cyrko, 2020-06-15:
[edit] It seems this issue has been expressed while I wrote this one. Sorry for the duplicate

Hi !

Thanks for your project ! It seems very promising however I think there needs to be an exhaust port on the mask. Since it is difficult to breathe through the filter, it would be greatly beneficial to expire effortlessly. It would also help to manage the humidity in the filter. I am speculating but I guess that a damp one would be less effective since the activated charcoal would be clogged up.

Here are some reference picture from a mask I used during my military service:

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
Behind the "grate" is a voice diaphragm. The two lower oppenings are the inlets and outlets. Each one of them houses a one way valve.

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
This is a close-up of the outlet

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
The gray opening is just the voice diaphragm.
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
The rubber of the valve is pretty thin so it may be possible to use balloons to make membranes. Their curved shape may be used to ensure a tight contact and mimic the bevel of the original one.
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

Regarding the nose and mouth separate area, it appears that its primary function is to unfog the lenses using fresh air. Since the eyes are extremely sensitive it makes sense to have only one effective seal around the mask.
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

Thanks again for your work and I hope to be able to help you further !

3devangelist, 2020-06-17:
I have made one for covid, to test out materials and use TPU,
https://wikifactory.com/+movimentomakerpt/diy-paper-mask

stephen304, 2020-06-17:
I made a lengthy comment on the previous issue about vent ports and some of the stuff we've been discussing in the discord channel. But I'll add a few comments based on what you've suggested:

* What are your thoughts on the importance of valves on both the filter and outlet? I think so far we've been discussing having just an exhale valve to prevent air intake when breathing in. When exhaling, the pressure difference should be relatively low if the vent port is working, but some humid air may go back through the filter. I'm not too knowledgeable about this
* For your balloon idea, would you like to design or spec out a valve based on this idea? We have a couple valve ideas in development, and plan on making them threaded so assemblers can choose a valve based on requirements and materials they have available. So if you could assist with a prototype using a balloon, we could add it to the options
* I'm not sure I completely understand the last part about airflow between the 2 sections of the mask - is the design of your mask so that air intake comes into the eye area and leaves from the mouth area? And is there a vent hole to allow free flow of air between the 2 chambers or do you think another one way valve would help to control the flow of humid air from exhaling reaching the eye area?

justinl681, 2020-06-18:
Hello! The design team and I are working on a one-way valve. If you'd like, check my pinned github page and give feedback!

stephen304, 2020-07-02:
There are now a couple of valve designs, one of which is tested, so I would suggest closing this issue and creating new ones for any remaining concerns

Closed 2020-07-02.

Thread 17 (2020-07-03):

Consider intake valve and/or inner mask valve

stephen304, 2020-07-03:
This gets mentioned every once in a while, so I'm just noting this here for when we have a full mask to test and evaluate whether an inner mask wall valve and/or inhale valve would help reduce fogging or improve the co2 situation.

Issue #5 has pictures of a commercial mask that seems to lack an inner mask valve.

Closed 2021-04-01.

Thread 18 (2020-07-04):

FullyPrintedValve diaphragm gets stuck in closed position

stephen304, 2020-07-04:
I've made a couple attempts to fix this, the first of which failed. Because there is a horizontal seam between the body and the inlet plate, there is often a small gap that the diaphragm can get stuck in. It's not a breaking issue since it will only get stuck on one side allowing it to let air by, but it would be nice if it didn't do that since it may reduce airflow.

Just creating this in case my second attempt to fix fails too.

Closed 2020-07-06.

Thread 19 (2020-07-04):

Test and establish procedure for face gasket

stephen304, 2020-07-04:
Weather stripping seems like a popular choice, we should test and document the available options to establish a recommended material and procedure for the face gasket

sophmur, 2020-08-01:
i'm working on a 3d printable rim that can be used to pull out to match most faces.
@stephen304 what's your thoughts?
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

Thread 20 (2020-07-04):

Additional valve designs

stephen304, 2020-07-04:
This is essentially an open invitation to anyone who wants to make new one way valve designs. Currently the only design in the repo is a more-or-less fully printed design that relies on having a smooth build surface and works best with a well calibrated first layer and flexible build plate (eg. smooth pei spring steel). We should also have valve designs that use more off-the-shelf parts to allow a wider number of makers to produce working one way valves.

The one way valve should be designed around the 40mm nato male reference model to ensure compatibility with all of the masks in the repo. The nato thread reference length and outer geometry should not be modified, however the design of the tightening knob on the end is up to the designer.

Potential one way valve ideas include:
* Using a circle cut from a balloon to make the flap
* Using a flat door that seals on an o-ring embedded in the surface
* A valve that has the same geometry as commercial mask valves, so that replacement diaphragms can be purchased in bulk and installed
* Using a commonly available spring or rubber band to create the mechanism for the valve

sophmur, 2020-08-01:
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

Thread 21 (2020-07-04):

Additional filter canister designs

stephen304, 2020-07-04:
The current canister designs we have are all pretty long. For cheek-mounted canisters, it would probably be nice to have a design more like a [pancake](https://user-images.githubusercontent.com/981915/86521846-d7b02700-be23-11ea-8d12-d0763951af3b.png).

We should also catalog these external designs somewhere (note: these are untested):
* https://www.thingiverse.com/thing:4236518
* https://www.thingiverse.com/thing:3858646

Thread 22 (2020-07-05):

FullyPrintedValve could have better airflow

stephen304, 2020-07-05:
I think this is due to the exhaust channel. I would like to figure out how to squeeze more parallel exhaust tubes into the end, since currently the total cross section of the 4 existing tubes is less than the area of the other holes (intake and port between exhaust tubes and valve chamber).

It could also be the holes in the diaphragm, I haven't checked. I'll return to look at this eventually since it works as is.

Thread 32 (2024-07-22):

Thread on right size nozzle input for mask wrong

TJRiley96, 2024-07-22:
The threads on the right side of the mask are going in the wrong direction. I don't have Fusion 360 to fix it.

stephen304, 2024-07-25:
Thanks for pointing that out - I managed to get it flipped and I updated the exported main stl in this PR #33

Let me know what you think

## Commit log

2020-06-15 Initial mask design
    [Canister.stl, Face shield gasket.stl]
2020-06-15 Added a disclaimer about pla and other dangerous materials
2020-06-18 Add filters folder to organize filter designs
2020-06-18 Add folders for other components, move original design to legacy folder
    [Canister.stl, Face shield gasket.stl]
2020-06-18 Hopefully all the formats
    [Trypophobic9000 (NATO mount) v7.f3z, Trypophobic9000 (NATO mount) v7.step, Trypophobic9000 Canister v7.stl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]
2020-06-18 Add general filters readme
2020-06-18 Adding the exported threads Stephen and co. made
    [Gas_Mask_Female_Thread v1.f3d, Gas_Mask_Female_Thread v1.step, Gas_Mask_Female_Thread v1.stl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]
2020-06-18 Added the endstop as per specification
    [Gas_Mask_Female_Thread_with_endstop v2.f3d, Gas_Mask_Female_Thread_with_endstop v2.step, Gas_Mask_Female_Thread_with_endstop v2.stl]
2020-06-18 Added a shortened version of the male thread
    To better fit the spec
    [Gas_Mask_Male_Thread_short v2.f3d, Gas_Mask_Male_Thread_short v2.step, Gas_Mask_Male_Thread_short v2.stl]
2020-06-18 Changing these out to add a chamfer
    [Gas_Mask_Female_Thread_with_endstop v4.f3d, Gas_Mask_Female_Thread_with_endstop v4.step, Gas_Mask_Female_Thread_with_endstop v4.stl]
2020-06-18 Added the renamed files
    [Gas_Mask_Female_Thread.f3d, Gas_Mask_Female_Thread.step, Gas_Mask_Female_Thread.stl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]
2020-06-18 Add catalog of thingiverse filter adapters
2020-06-19 Add clarification that valves are not ready
2020-06-20 Screwed that up
2020-06-20 Added the Typophobic Lid
    [Trypophopic9000.f3d, Trypophopic9000.step, Trypophopic9000.stl]
2020-06-20 Added the Serious files
    [SeriousOne.f3z, SeriousOne.step, SeriousOne.stl]
2020-06-20 Uploaded the 120mm canister
    [120mm_Canister (NATO mount).f3z, 120mm_Canister (NATO mount).step, 120mm_Canister (NATO mount).stl]
2020-06-22 Update nato thread reference
    Add hole in male thread according to standard
    Remove chamfer from bottom of male thread
    [Gas_Mask_Female_Thread.f3d, Gas_Mask_Female_Thread.step, Gas_Mask_Female_Thread.stl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]
2020-06-22 Rename thread references to a more descriptive name. Add more detailed documentation.
    [NATO_40mm_Thread_Female.f3d, NATO_40mm_Thread_Female.stl, NATO_40mm_Thread_Female.stp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]
2020-06-23 Add printed valve prototype
    [FullyPrintedValve.f3z, FullyPrintedValve.stl, FullyPrintedValve.stp]
2020-06-28 Switch to NATO ports on the mask
    [face_shield_gasket.stl]
2020-06-29 Adjust height and position of right port to be more symmetrical
    [face_shield_gasket.stl]
2020-07-05 Improve airflow, make inlet plate flush, add divot to help tape trimming, add exhaust channel.
    Add fullyprintedvalve test results and improve documentation
    Reduce knob chamfer for better print quality, larger knob cuts for comfort, angle valve chamber seam to prevent diaphragm sticking (fixes #18)
    [FullyPrintedValve.f3z, FullyPrintedValve.stl, FullyPrintedValve.stp]
2020-07-06 FullyPrintedValve: Add testing step to the end of assembly
2020-07-06 FullyPrintedValve: Split stl apart
    [FullyPrintedValve-Diaphragm.stl, FullyPrintedValve-Inlet.stl, FullyPrintedValve.stl]
2020-07-06 Docs: Remove valve warning, add discord link, remove outdated valve text
2021-03-09 feat: Add SplineRespirator
    [SplineRespirator.f3z, SplineRespirator.step]
2021-03-12 Am I doing this right?
    Is this how you GitHub?
    [BalloonValve-Inlet.stl, BalloonValve.f3z, BalloonValve.step]
2021-03-12 Added the Balloon Valve
2021-03-29 feat: Add BottleFilterAdapter
    [BottleFilterAdapter.f3z, BottleFilterAdapter.stl]
2021-03-29 docs: Add thread reference link to BottleFilterAdapter
2021-03-31 fix: Improve BottleFilterAdapter seal with spot for US number 18 o-ring
    [BottleFilterAdapter.f3z, BottleFilterAdapter.stl]
2021-04-01 docs: Update nato filters readme descriptions
